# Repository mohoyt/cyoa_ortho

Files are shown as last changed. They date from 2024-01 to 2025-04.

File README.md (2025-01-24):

# CYOA (Choose Your Own Adventure) Ortho

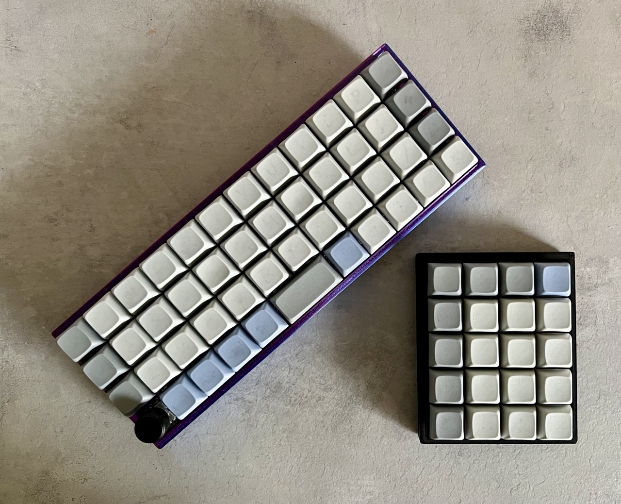
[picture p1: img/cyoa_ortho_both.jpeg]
CYOA Ortho


CYOA Ortho or Choose Your Own Adventure Ortho is a simple Pro Micro compatible ortho PCB that you can freely adjust to your preferences by snapping off rows or columns to make your perfect Ortho board. 

The board is a 5 row x 12 column board to begin with but with the perforations on the board you can make it almost any size down to 3 x 3. So you can build ortho layouts like the Preonic (5x12), Planck (4x12), Gherkin (3x10) or even a macro or num pad.

If you go with a 4 or a 5 row variant then you have the option to have 1 or 2 2u keys on the bottom row too.

A single optional rotary encoder can be added in one of 8 positions. Supports MX or choc v1 (and v2 (since CYOA v0.4)) switches. 

See the KLE layout here: [http://www.keyboard-layout-editor.com/#/gists/a172a36ed405e7bec95fd89415a75808](http://www.keyboard-layout-editor.com/#/gists/a172a36ed405e7bec95fd89415a75808)

## Where to get one

Limited PCBs are available at STHLM kb: [https://sthlmkb.com/shop/cyoa-ortho/](https://sthlmkb.com/shop/cyoa-ortho/)

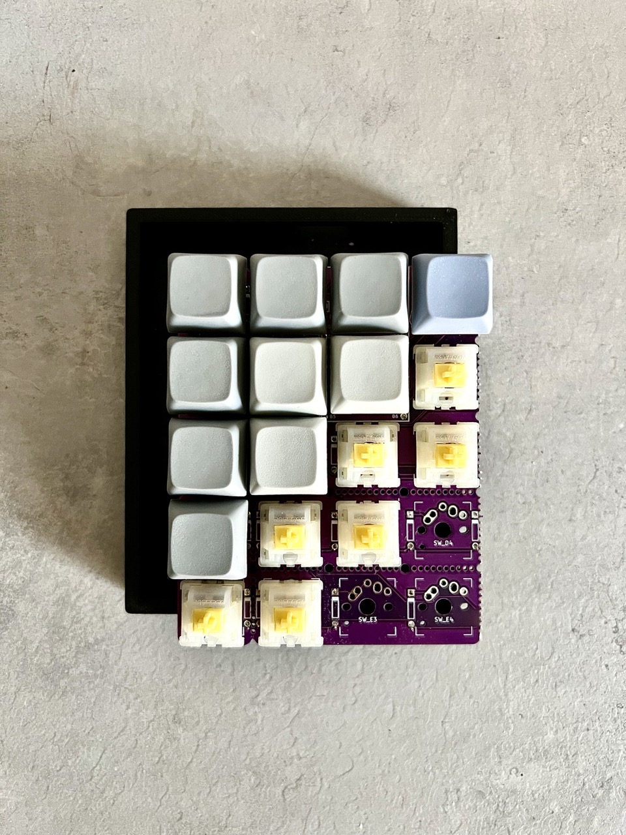
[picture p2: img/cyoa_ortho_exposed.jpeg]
CYOA Ortho


## Build instructions

These are printed on the PCB. The build is pretty simple.

1. Decide what size board you want
2. Carefully snap along perforations on PCB. It helps to use a flush cutter to help start at each end and then to use the edge of a table to assist with bending and snapping. FR4 is sharp so be careful and make sure to sand or file the edges to smoothen them
3. Solder the diodes (either side is technically fine) just make sure that you have the right orientation for them. The black stripe on the diode should line up with the white stripe on the top of the board
4. Solder the 2 switches directly above the controller. Trim the pins and isolate them with electrical tape after so that they do not short on the controller.
5. Flash and solder the controller onto the board. You want the controller to be as close as possible to the board so that it doesn't clash with any case that you're using. Make sure to plug in the board and test all the switch contacts (e.g. with tweezers) once you have done this. 
6. Install stabilisers (if you're using them), encoder (again, if you're using one) and      switches on the rest of the board.
7. Install in case. Enjoy.  

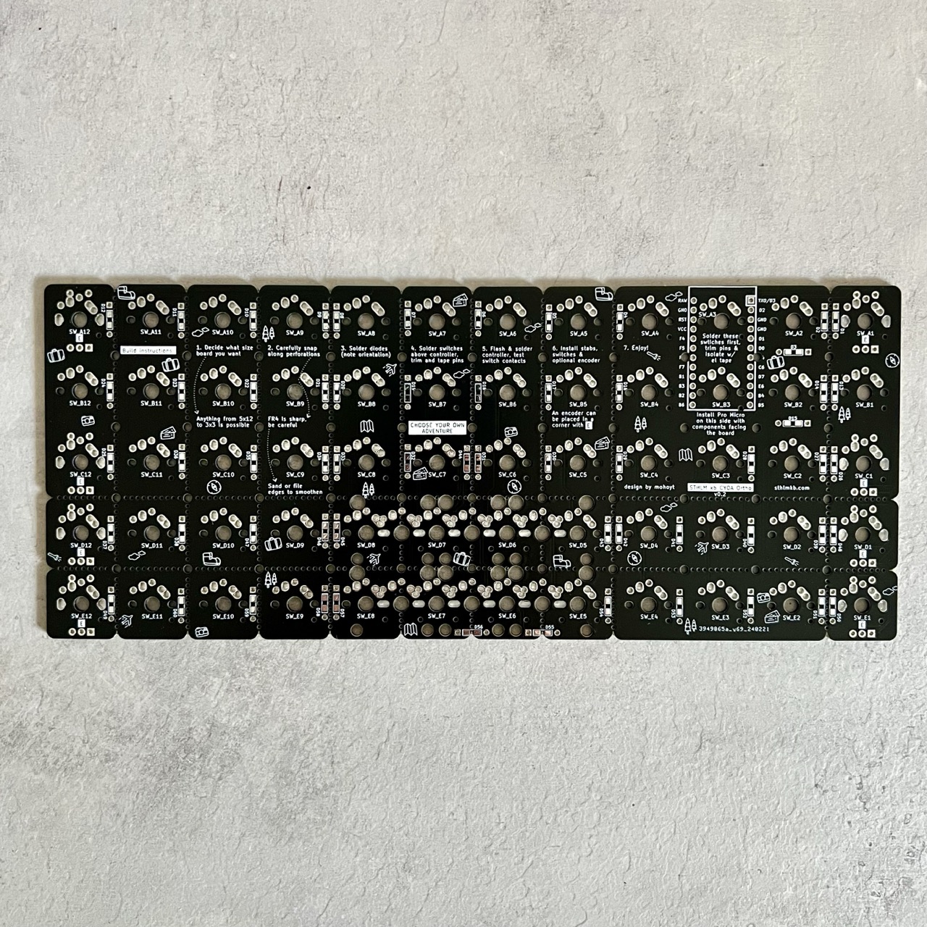
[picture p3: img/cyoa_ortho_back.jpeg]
CYOA Ortho


## Flashing instructions

See the firmware folder for more information.

There are example qmk files for 5x12 and 4x12 layouts for both QMK and Vial setups. These will need to be compiled using QMK or the Vial fork of Vial respectively. The `info.json` file contains all possible layouts so it should be possible to easily craft your layout using that as a starting point. 

## Plates

The CYOA Ortho is a bare PCB with no plate. It is theoretically possible to make a plate for it, and probably not hard either since it is a grid. A plate for a Planck or a Preonic could also be used if you have the same size.

## Cases

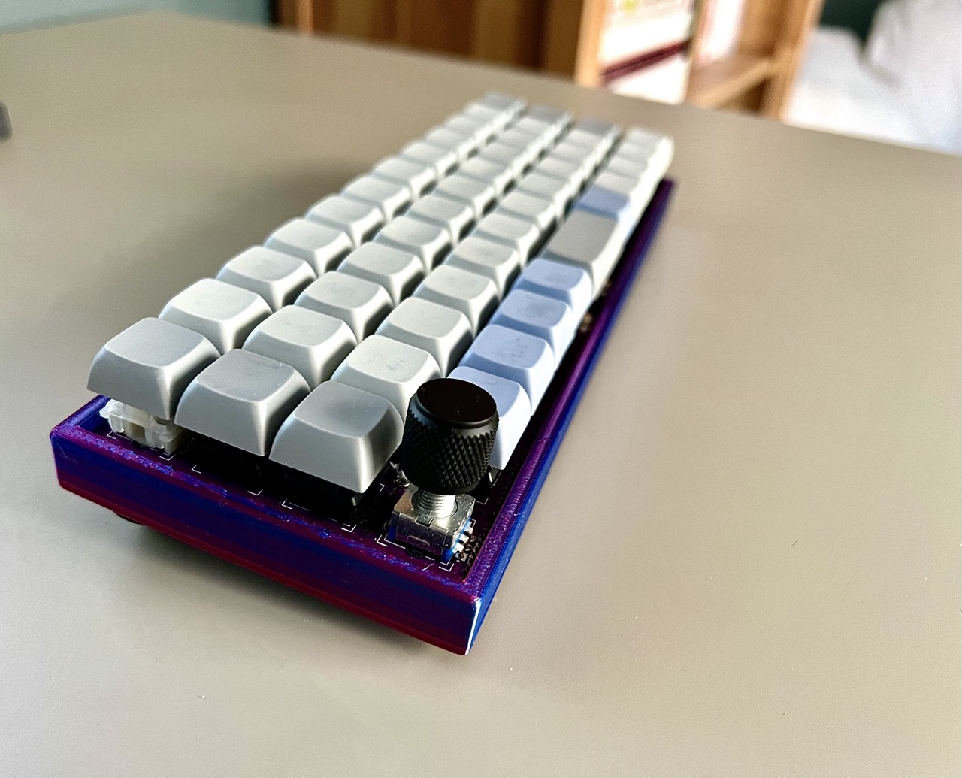
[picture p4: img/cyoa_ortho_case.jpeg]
CYOA Ortho


3d printed cases are available for CYOA Ortho. See here for more details: [https://www.printables.com/model/784492-cyoa-choose-your-own-adventure-ortho-keyboard-case](https://www.printables.com/model/784492-cyoa-choose-your-own-adventure-ortho-keyboard-case) These are tray style and attach to the M2 holes on the PCB. Cases are available for all possible size variations.

## Changelog / known issues

- Version 0.1 had the wrong size Pro Micro footprint. This is updated in v0.2
- Version 0.2 had a trace not connected fully meaning that the four leftmost keys on the 4th row would not work. This is fixed in version 0.3
- Version 0.4 now has larger centre holes for Choc v2 switches (currently untested though)

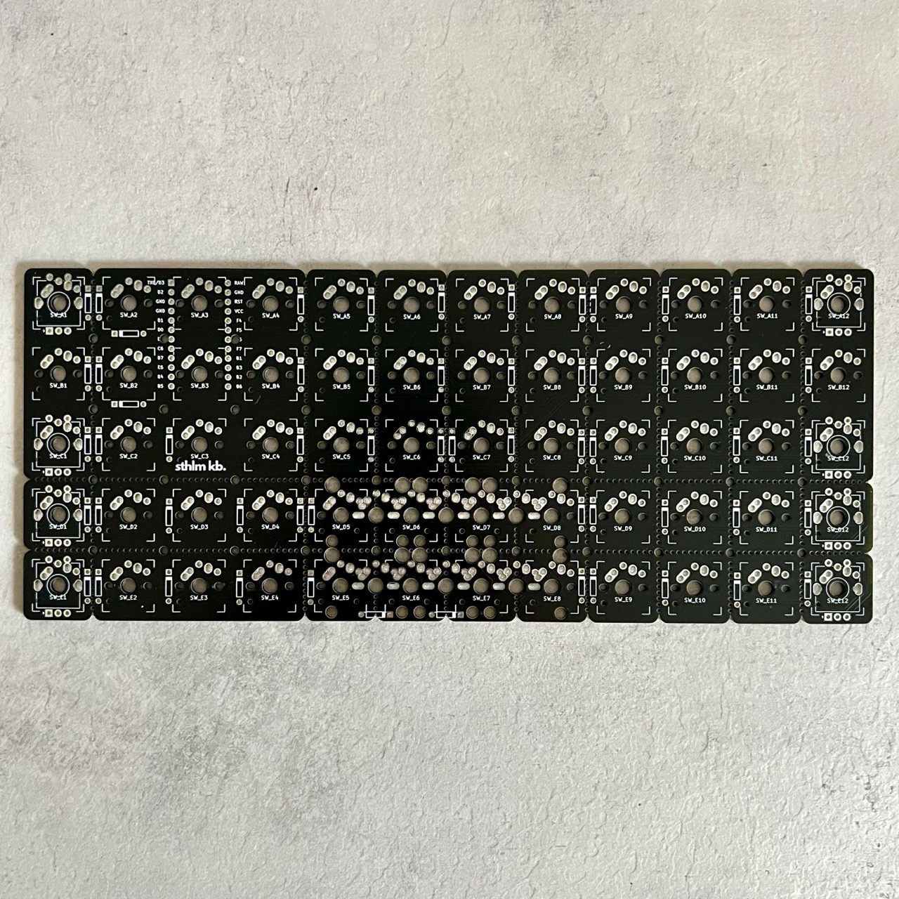
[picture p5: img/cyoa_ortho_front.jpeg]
CYOA Ortho


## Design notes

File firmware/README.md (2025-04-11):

# CYOA Ortho

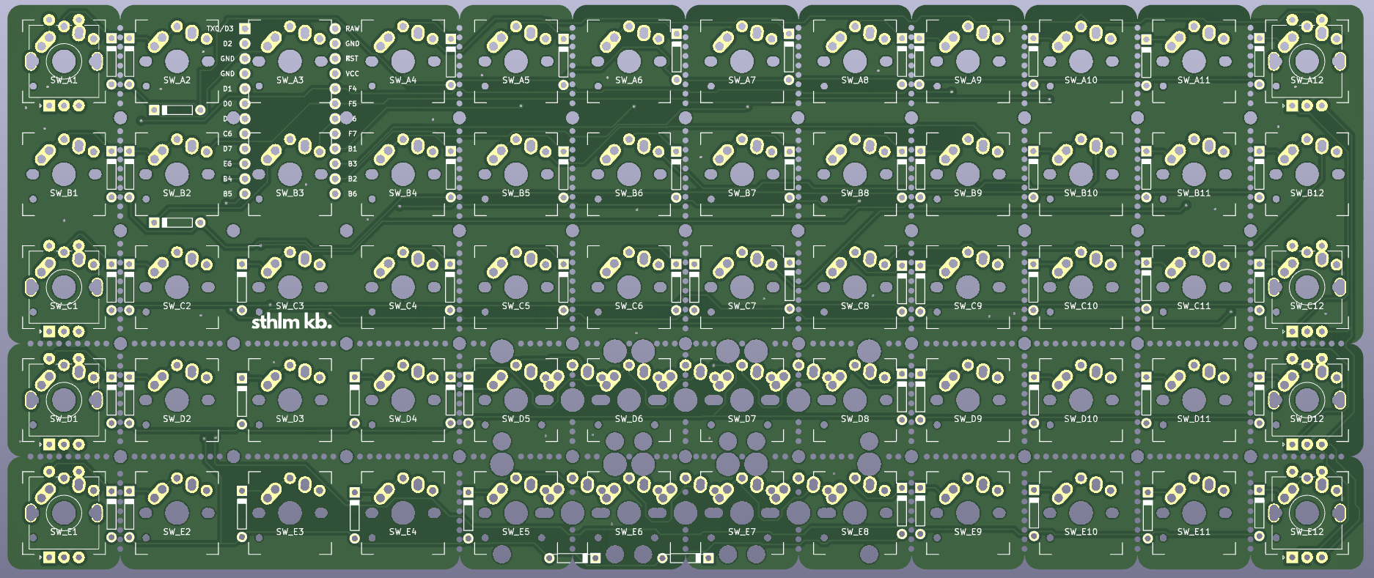
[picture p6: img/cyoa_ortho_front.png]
CYOA Ortho


## Flashing instructions

See the `cyoa_ortho` folder for the QMK source.

There are example qmk files for 5x12 and 4x12 layouts for both QMK and Vial setups. These will need to be compiled using QMK or the Vial fork of Vial respectively. The `info.json` file contains all possible layouts so it should be possible to easily craft your layout using that as a starting point. 

## Precompiled firmware

There are a couple precompiled firmware examples here that you are welcome to use: 

* QMK 5x12 layout (for Pro Micro)
* QMK 4x12 layout (for Pro Micro)
* Vial 5x12 layout (for Pro Micro)
* Vial 5x12 layout (for RP2040 Helios board)
* Vial 4x12 layout (for Pro Micro)
* Vial 4x12 layout (for RP2040 Helios board)

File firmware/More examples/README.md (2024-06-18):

# CYOA Ortho

CYOA Ortho

## More examples

This is an example of how you might repurpose the encoder pin (if you're not using encoders) to add rgb lights.

In this case I used pin D3, but you can of course change it to use the other pin D2.

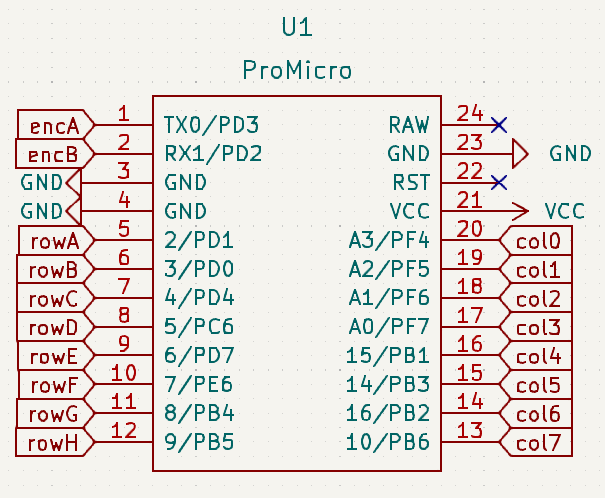
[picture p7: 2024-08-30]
img/cyoa_pinout.png

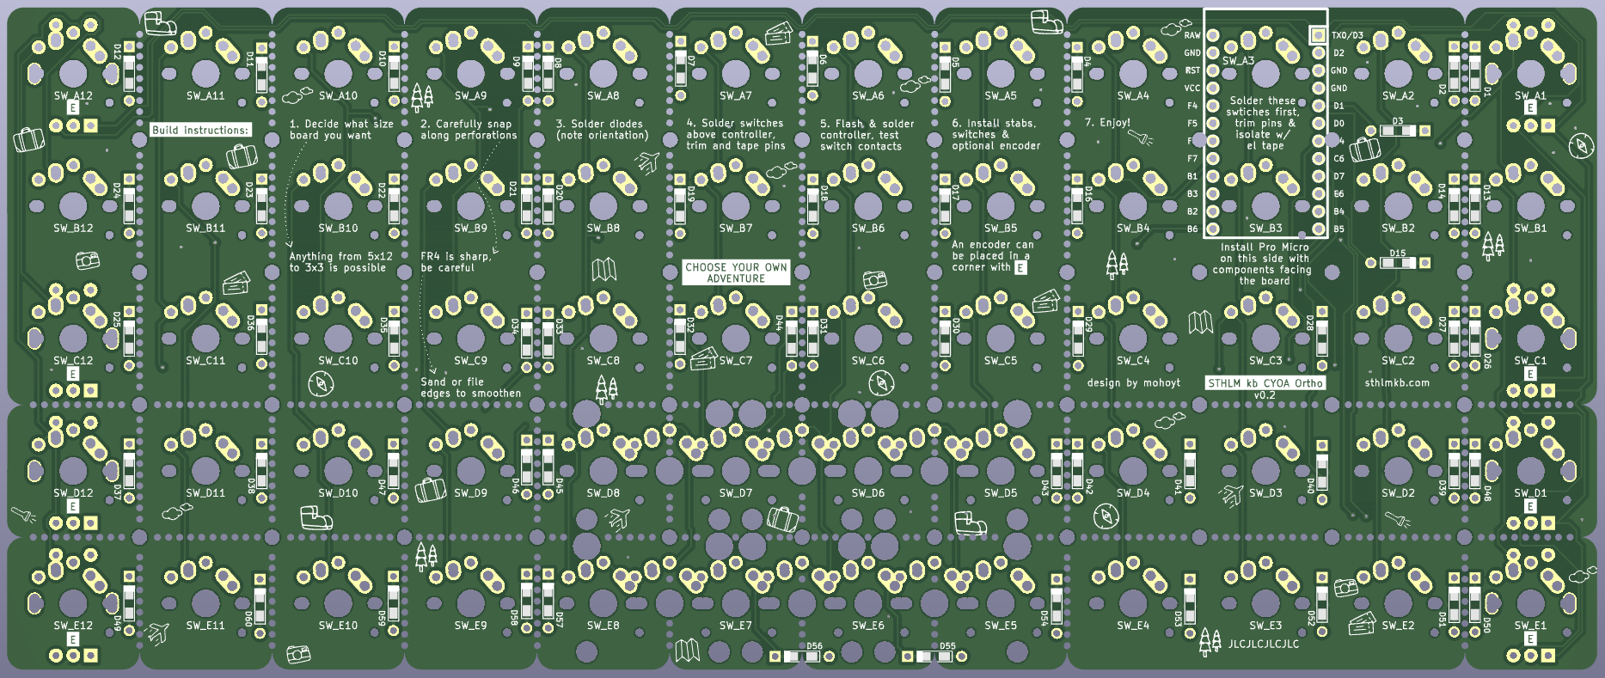
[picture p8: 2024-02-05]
img/cyoa_ortho_back.png

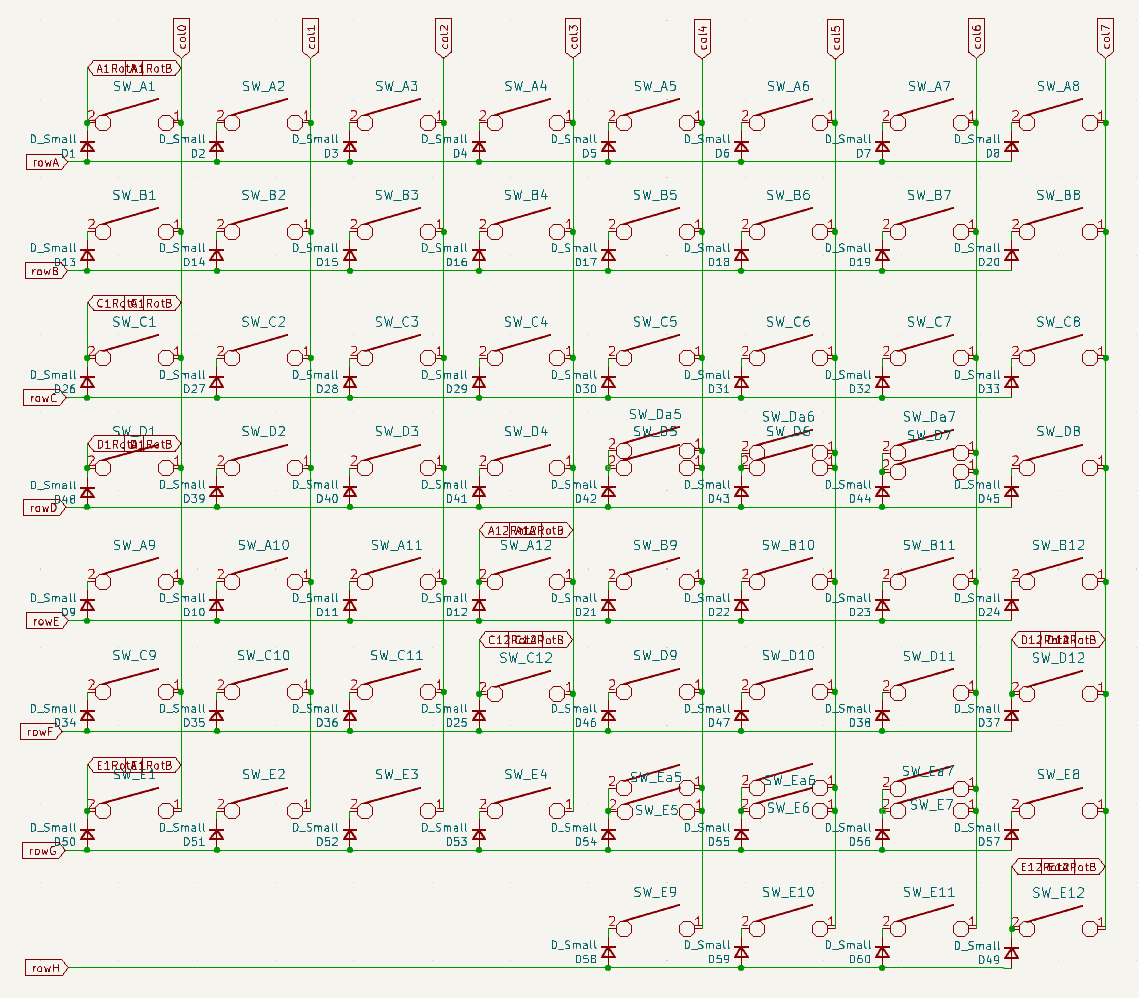
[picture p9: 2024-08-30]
img/cyoa_matrix.png

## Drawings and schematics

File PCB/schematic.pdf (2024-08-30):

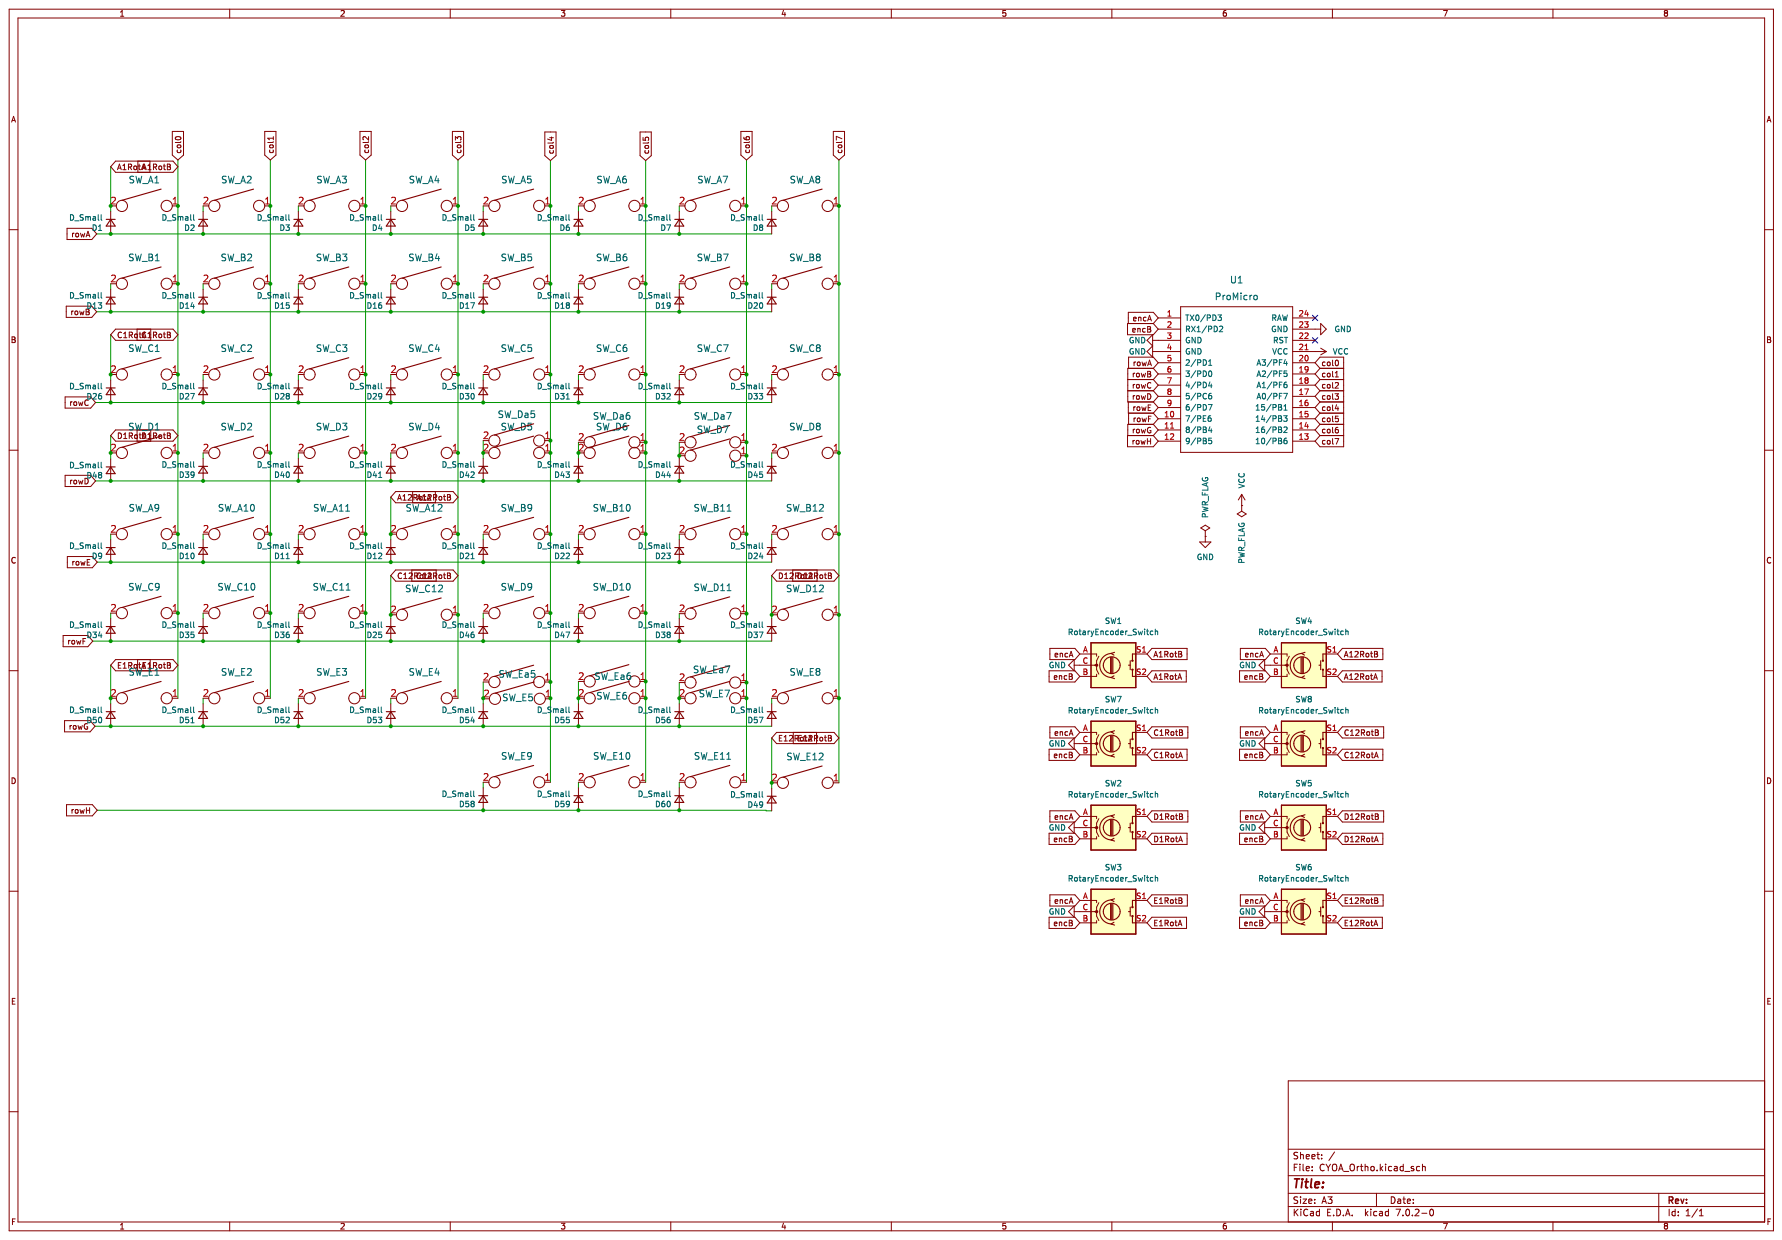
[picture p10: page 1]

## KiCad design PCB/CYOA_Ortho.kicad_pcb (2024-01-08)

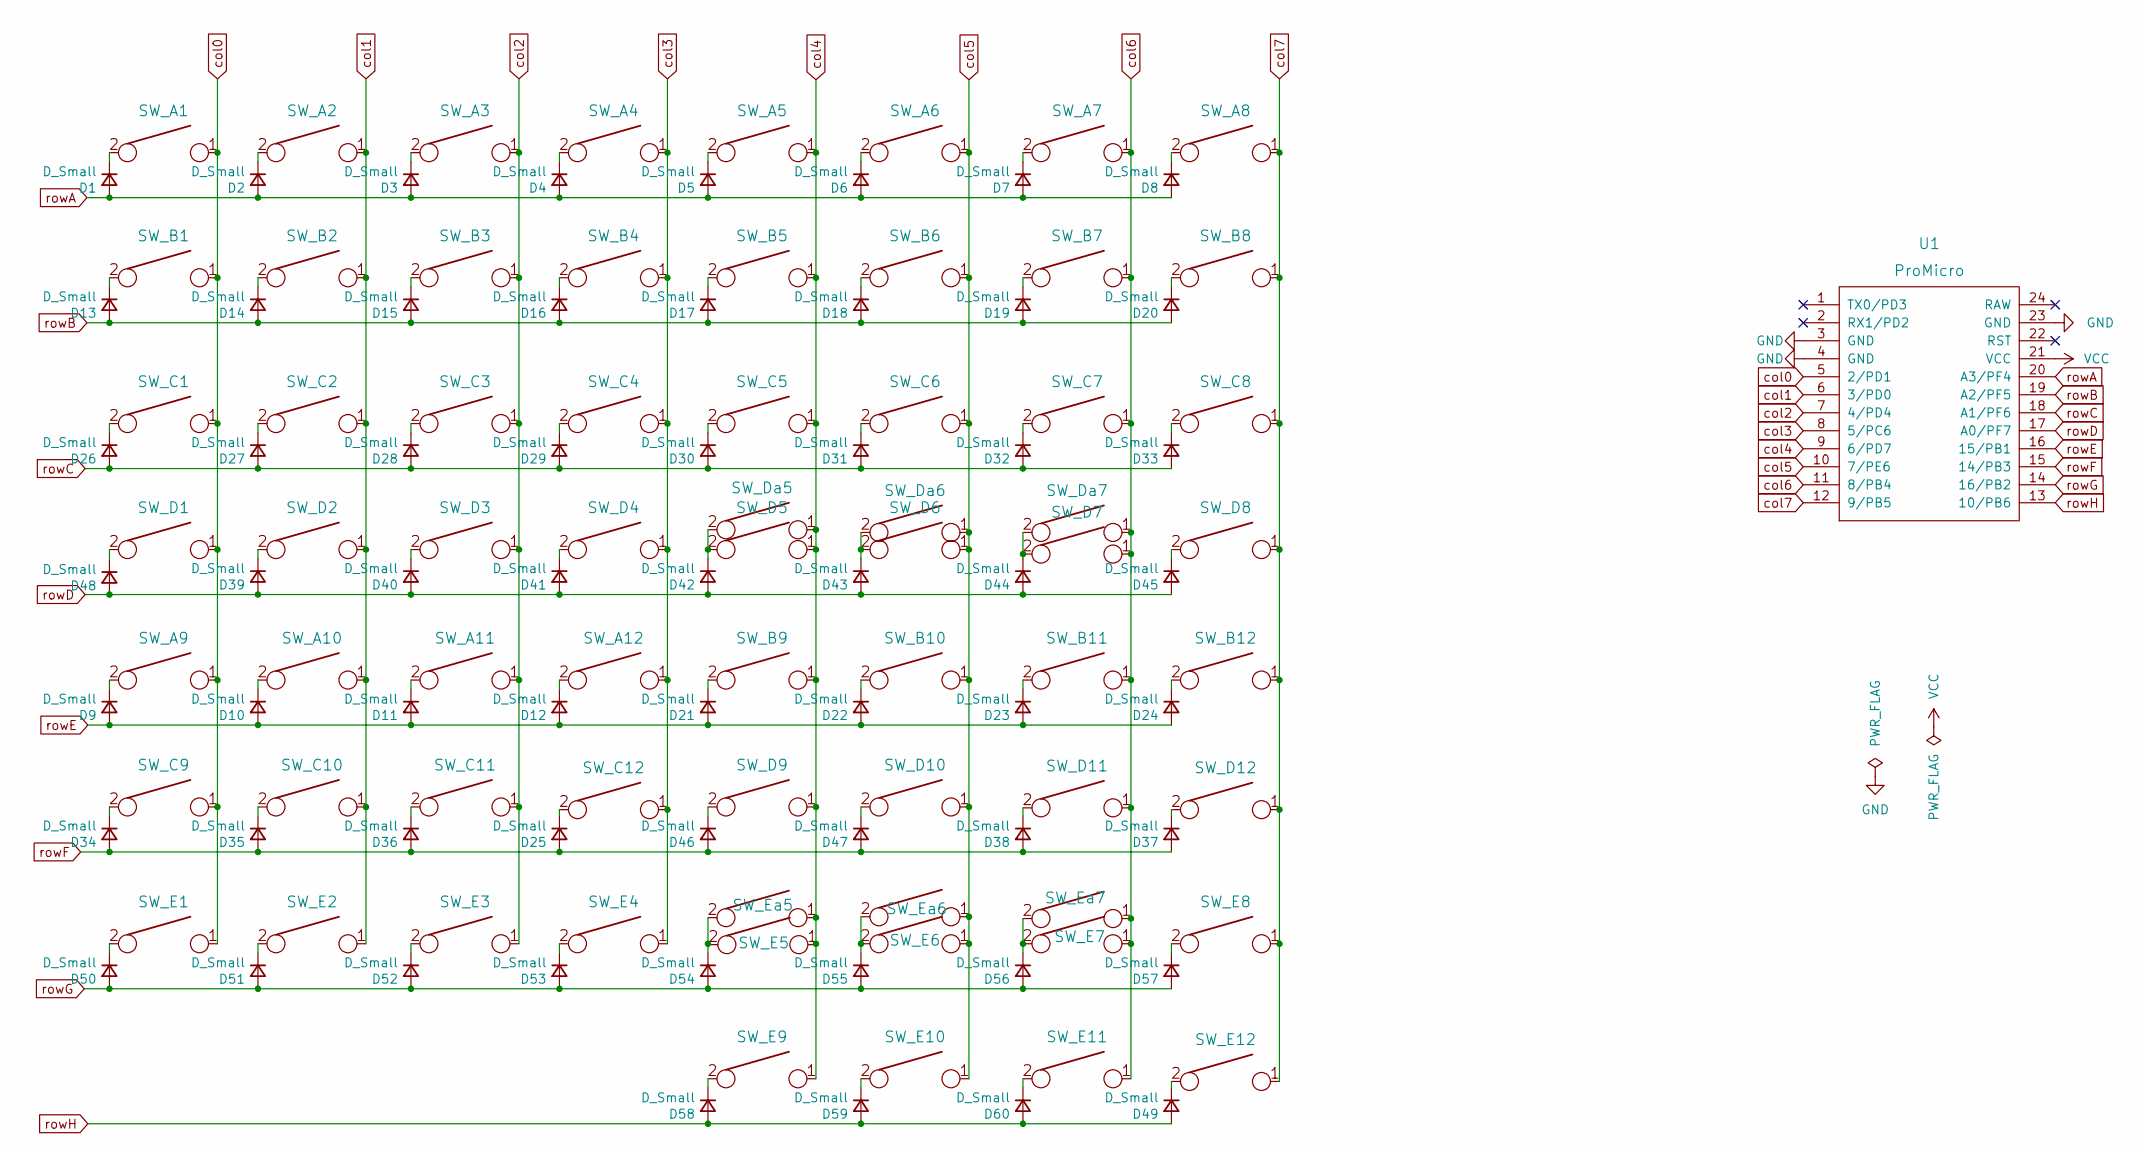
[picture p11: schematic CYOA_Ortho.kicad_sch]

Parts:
D1, D2, D3, D4, D5, D6, D7, D8, D9, D10, D11, D12, D13, D14, D15, D16, D17, D18, D19, D20, D21, D22, D23, D24, D25, D26, D27, D28, D29, D30, D31, D32, D33, D34, D35, D36, D37, D38, D39, D40, D41, D42, D43, D44, D45, D46, D47, D48, D49, D50, D51, D52, D53, D54, D55, D56, D57, D58, D59, D60: D_Small; Diode-Hybrid-Back
SW_A1, SW_A2, SW_A3, SW_A4, SW_A5, SW_A6, SW_A7, SW_A8, SW_A9, SW_A10, SW_A11, SW_A12: KEYSW; MX-Alps-Choc-1U-NoLED
SW_B1, SW_B2, SW_B3, SW_B4, SW_B5, SW_B6, SW_B7, SW_B8, SW_B9, SW_B10, SW_B11, SW_B12: KEYSW; MX-Alps-Choc-1U-NoLED
SW_C1, SW_C2, SW_C3, SW_C4, SW_C5, SW_C6, SW_C7, SW_C8, SW_C9, SW_C10, SW_C11, SW_C12: KEYSW; MX-Alps-Choc-1U-NoLED
SW_D1, SW_D2, SW_D3, SW_D4, SW_D5, SW_D6, SW_D7, SW_D8, SW_D9, SW_D10, SW_D11, SW_D12: KEYSW; MX-Alps-Choc-1U-NoLED
SW_Da5, SW_Da6, SW_Da7: KEYSW; MX-Alps-Choc-2U-StabFlip-NoLED
SW_E1, SW_E2, SW_E3, SW_E4, SW_E5, SW_E6, SW_E7, SW_E8, SW_E9, SW_E10, SW_E11, SW_E12: KEYSW; MX-Alps-Choc-1U-NoLED
SW_Ea5, SW_Ea6, SW_Ea7: KEYSW; MX-Alps-Choc-2U-StabFlip-NoLED
U1: ProMicro; ArduinoProMicro-Mini-USB

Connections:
GND: U1.3 (GND), U1.4 (GND), U1.23 (GND)
unnamed: D1.1 (K), SW_A1.2
unnamed: D2.1 (K), SW_A2.2
unnamed: D3.1 (K), SW_A3.2
unnamed: D4.1 (K), SW_A4.2
unnamed: D5.1 (K), SW_A5.2
unnamed: D6.1 (K), SW_A6.2
unnamed: D7.1 (K), SW_A7.2
unnamed: D8.1 (K), SW_A8.2
unnamed: D9.1 (K), SW_A9.2
unnamed: D10.1 (K), SW_A10.2
unnamed: D11.1 (K), SW_A11.2
unnamed: D12.1 (K), SW_A12.2
unnamed: D13.1 (K), SW_B1.2
unnamed: D14.1 (K), SW_B2.2
unnamed: D15.1 (K), SW_B3.2
unnamed: D16.1 (K), SW_B4.2
unnamed: D17.1 (K), SW_B5.2
unnamed: D18.1 (K), SW_B6.2
unnamed: D19.1 (K), SW_B7.2
unnamed: D20.1 (K), SW_B8.2
unnamed: D21.1 (K), SW_B9.2
unnamed: D22.1 (K), SW_B10.2
unnamed: D23.1 (K), SW_B11.2
unnamed: D24.1 (K), SW_B12.2
unnamed: D25.1 (K), SW_C12.2
unnamed: D26.1 (K), SW_C1.2
unnamed: D27.1 (K), SW_C2.2
unnamed: D28.1 (K), SW_C3.2
unnamed: D29.1 (K), SW_C4.2
unnamed: D30.1 (K), SW_C5.2
unnamed: D31.1 (K), SW_C6.2
unnamed: D32.1 (K), SW_C7.2
unnamed: D33.1 (K), SW_C8.2
unnamed: D34.1 (K), SW_C9.2
unnamed: D35.1 (K), SW_C10.2
unnamed: D36.1 (K), SW_C11.2
unnamed: D37.1 (K), SW_D12.2
unnamed: D38.1 (K), SW_D11.2
unnamed: D39.1 (K), SW_D2.2
unnamed: D40.1 (K), SW_D3.2
unnamed: D41.1 (K), SW_D4.2
unnamed: D42.1 (K), SW_D5.2, SW_Da5.2
unnamed: D43.1 (K), SW_D6.2, SW_Da6.2
unnamed: D44.1 (K), SW_D7.2, SW_Da7.2
unnamed: D45.1 (K), SW_D8.2
unnamed: D46.1 (K), SW_D9.2
unnamed: D47.1 (K), SW_D10.2
unnamed: D48.1 (K), SW_D1.2
unnamed: D49.1 (K), SW_E12.2
unnamed: D50.1 (K), SW_E1.2
unnamed: D51.1 (K), SW_E2.2
unnamed: D52.1 (K), SW_E3.2
unnamed: D53.1 (K), SW_E4.2
unnamed: D54.1 (K), SW_E5.2, SW_Ea5.2
unnamed: D55.1 (K), SW_E6.2, SW_Ea6.2
unnamed: D56.1 (K), SW_E7.2, SW_Ea7.2
unnamed: D57.1 (K), SW_E8.2
unnamed: D58.1 (K), SW_E9.2
unnamed: D59.1 (K), SW_E10.2
unnamed: D60.1 (K), SW_E11.2
VCC: U1.21 (VCC)
col0: SW_A1.1, SW_A9.1, SW_B1.1, SW_C1.1, SW_C9.1, SW_D1.1, SW_E1.1, U1.5 (2/PD1)
col1: SW_A2.1, SW_A10.1, SW_B2.1, SW_C2.1, SW_C10.1, SW_D2.1, SW_E2.1, U1.6 (3/PD0)
col2: SW_A3.1, SW_A11.1, SW_B3.1, SW_C3.1, SW_C11.1, SW_D3.1, SW_E3.1, U1.7 (4/PD4)
col3: SW_A4.1, SW_A12.1, SW_B4.1, SW_C4.1, SW_C12.1, SW_D4.1, SW_E4.1, U1.8 (5/PC6)
col4: SW_A5.1, SW_B5.1, SW_B9.1, SW_C5.1, SW_D5.1, SW_D9.1, SW_Da5.1, SW_E5.1, SW_E9.1, SW_Ea5.1, U1.9 (6/PD7)
col5: SW_A6.1, SW_B6.1, SW_B10.1, SW_C6.1, SW_D6.1, SW_D10.1, SW_Da6.1, SW_E6.1, SW_E10.1, SW_Ea6.1, U1.10 (7/PE6)
col6: SW_A7.1, SW_B7.1, SW_B11.1, SW_C7.1, SW_D7.1, SW_D11.1, SW_Da7.1, SW_E7.1, SW_E11.1, SW_Ea7.1, U1.11 (8/PB4)
col7: SW_A8.1, SW_B8.1, SW_B12.1, SW_C8.1, SW_D8.1, SW_D12.1, SW_E8.1, SW_E12.1, U1.12 (9/PB5)
rowA: D1.2 (A), D2.2 (A), D3.2 (A), D4.2 (A), D5.2 (A), D6.2 (A), D7.2 (A), D8.2 (A), U1.20 (A3/PF4)
rowB: D13.2 (A), D14.2 (A), D15.2 (A), D16.2 (A), D17.2 (A), D18.2 (A), D19.2 (A), D20.2 (A), U1.19 (A2/PF5)
rowC: D26.2 (A), D27.2 (A), D28.2 (A), D29.2 (A), D30.2 (A), D31.2 (A), D32.2 (A), D33.2 (A), U1.18 (A1/PF6)
rowD: D39.2 (A), D40.2 (A), D41.2 (A), D42.2 (A), D43.2 (A), D44.2 (A), D45.2 (A), D48.2 (A), U1.17 (A0/PF7)
rowE: D9.2 (A), D10.2 (A), D11.2 (A), D12.2 (A), D21.2 (A), D22.2 (A), D23.2 (A), D24.2 (A), U1.16 (15/PB1)
rowF: D25.2 (A), D34.2 (A), D35.2 (A), D36.2 (A), D37.2 (A), D38.2 (A), D46.2 (A), D47.2 (A), U1.15 (14/PB3)
rowG: D50.2 (A), D51.2 (A), D52.2 (A), D53.2 (A), D54.2 (A), D55.2 (A), D56.2 (A), D57.2 (A), U1.14 (16/PB2)
rowH: D49.2 (A), D58.2 (A), D59.2 (A), D60.2 (A), U1.13 (10/PB6)

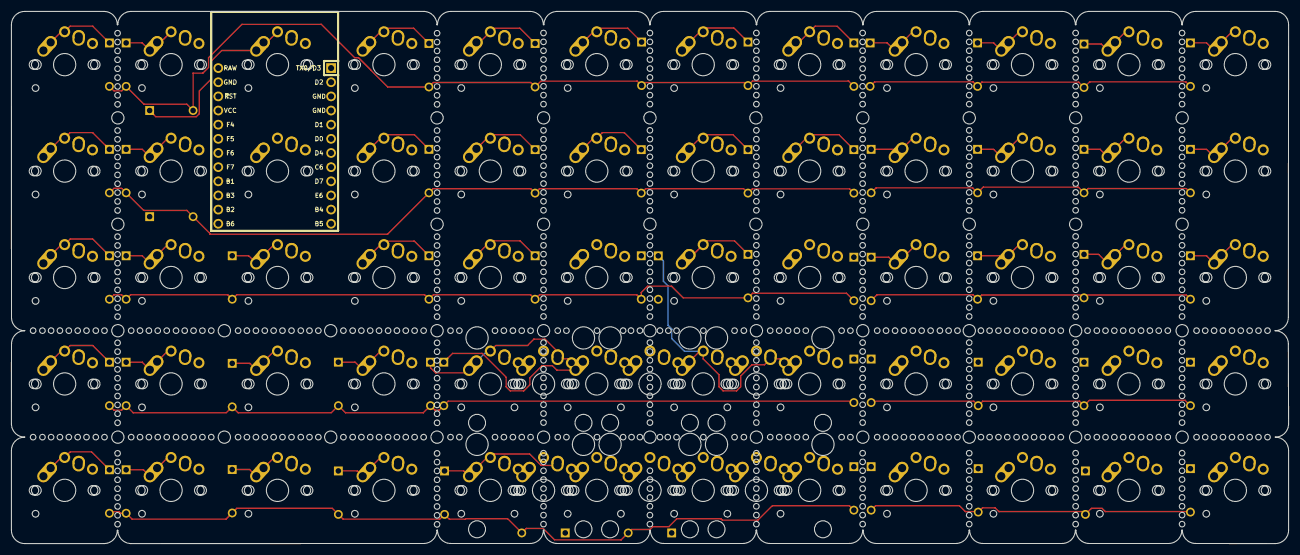
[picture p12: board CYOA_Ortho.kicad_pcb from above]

Board: 2 copper layers, 229.2 x 95.5 mm, 127 parts (1 on the bottom side), 77 nets.

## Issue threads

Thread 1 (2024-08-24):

Trouble flashing the firmware

rodgzilla, 2024-08-24:
Hi!

I am having troubles flashing the firmware onto the controller. I am quite new to QMK so there are probably things that I don't understand.

I've run the following command and this is the result I am getting.

```
 make sthlmkb/cyoa_ortho:default
```

```
QMK Firmware 0.25.22
make: *** No rule to make target 'sthlmkb/cyoa_ortho:default'. Stop.
|
| QMK's make format is:
|     make keyboard_folder:keymap_folder[:target]
|
| Where `keyboard_folder` is the path to the keyboard relative to
| `qmk_firmware/keyboards/`, and `keymap_folder` is the name of the
| keymap folder under that board's `keymaps/` directory.
|
| Examples:
|     keyboards/dz60, keyboards/dz60/keymaps/default
|       -> make dz60:default
|       -> qmk compile -kb dz60 -km default
|     keyboards/planck/rev6, keyboards/planck/keymaps/default
|       -> make planck/rev6:default:flash
|       -> qmk flash -kb planck/rev6 -km default
|
```

I think that my QMK environment is setup properly because I have managed to flash other keyboards in the past.

I have also tried copying the content of folder `cyoa_ortho/firmware/cyoa_ortho` to the `keyboards/sthlmkb` in my QMK folder but I keep getting the same message.

Could you please give me some pointers?

mohoyt, 2024-08-25:
Hey!

A couple things to try:
* Are you sure that you're in the `qmk_firmware` directory when you run the command?
* Have you copied over the `default` keymap too? I assume that you copied that over automatically when you got the whole folder, but just want to check!
* Is your QMK installed correctly? You can run `qmk doctor` to check this
* Have you tried running `qmk compile -kb sthlmkb/cyoa_ortho -km default` instead? That also worked for me

Maybe as another option is updating QMK so that you have the latest version (though it looks like you do from above) or reinstalling it if that doesn't work.

Let me know how you get on and hopefully we can figure this out!

mohoyt, 2025-01-24:
Closed due to inactivity.

Closed 2025-01-24.

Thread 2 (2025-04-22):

Question: stabilizers

timvyy, 2025-04-22:
Hey,

do I need screw in or snap in stabilizers for the CYOA keyboard PCB?

Thanks

mohoyt, 2025-04-23:
Hey! For the 2u keys you can use either, they just need to be PCB mount ones and not plate mount.

timvyy, 2025-04-23:
Thanks!

Closed 2025-04-23.

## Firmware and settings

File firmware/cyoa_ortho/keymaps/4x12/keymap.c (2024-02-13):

/* Copyright 2024 mohoyt
 *
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
 * You should have received a copy of the GNU General Public License
 * along with this program.  If not, see <http://www.gnu.org/licenses/>.
 */
#include QMK_KEYBOARD_H

enum layers {
  _QWERTY,
  _LOWER,
  _RAISE
};

const uint16_t PROGMEM keymaps[][MATRIX_ROWS][MATRIX_COLS] = {

/* Qwerty
 * ,-----------------------------------------------------------------------------------.
 * | Esc  |   Q  |   W  |   E  |   R  |   T  |   Y  |   U  |   I  |   O  |   P  | Bcsp |
 * |------+------+------+------+------+-------------+------+------+------+------+------|
 * | Tab  |   A  |   S  |   D  |   F  |   G  |   H  |   J  |   K  |   L  |   ;  |  "   |
 * |------+------+------+------+------+------|------+------+------+------+------+------|
 * | Shift|   Z  |   X  |   C  |   V  |   B  |   N  |   M  |   ,  |   .  |   /  |Enter |
 * |------+------+------+------+------+------+------+------+------+------+------+------|
 * | Mute | Ctrl | Alt  | GUI  |Lower |    Space    |Raise | Left | Down |  Up  |Right |
 * `-----------------------------------------------------------------------------------'
 */
[_QWERTY] = LAYOUT_4x12(
  KC_ESC,  KC_Q,    KC_W,    KC_E,    KC_R,    KC_T,    KC_Y,    KC_U,    KC_I,    KC_O,    KC_P,    KC_BSPC,
  KC_TAB,  KC_A,    KC_S,    KC_D,    KC_F,    KC_G,    KC_H,    KC_J,    KC_K,    KC_L,    KC_SCLN, KC_QUOT,
  KC_LSFT, KC_Z,    KC_X,    KC_C,    KC_V,    KC_B,    KC_N,    KC_M,    KC_COMM, KC_DOT,  KC_SLSH, KC_ENT,
  KC_MUTE, KC_LCTL, KC_LALT, KC_LGUI, MO(1),   KC_SPC,  KC_SPC,  MO(2),   KC_LEFT, KC_DOWN, KC_UP,   KC_RGHT
),

/* Lower
 * ,-----------------------------------------------------------------------------------.
 * |   ~  |   !  |   @  |   #  |   $  |   %  |   ^  |   &  |   *  |   (  |   )  | Del  |
 * |------+------+------+------+------+-------------+------+------+------+------+------|
 * | Del  |  F1  |  F2  |  F3  |  F4  |  F5  |  F6  |   _  |   +  |   {  |   }  |  |   |
 * |------+------+------+------+------+------|------+------+------+------+------+------|
 * |      |  F7  |  F8  |  F9  |  F10 |  F11 |  F12 |ISO ~ |ISO | | Home | End  |      |
 * |------+------+------+------+------+------+------+------+------+------+------+------|
 * |      |      |      |      |      |             |      | Next | Vol- | Vol+ | Play |
 * `-----------------------------------------------------------------------------------'
 */
[_LOWER] = LAYOUT_4x12(
  KC_TILD, KC_EXLM, KC_AT,   KC_HASH, KC_DLR,  KC_PERC, KC_CIRC, KC_AMPR, KC_ASTR, KC_LPRN, KC_RPRN, KC_DEL,
  KC_DEL,  KC_F1,   KC_F2,   KC_F3,   KC_F4,   KC_F5,   KC_F6,   KC_UNDS, KC_PLUS, KC_LCBR, KC_RCBR, KC_PIPE,
  _______, KC_F7,   KC_F8,   KC_F9,   KC_F10,  KC_F11,  KC_F12,S(KC_NUHS),S(KC_NUBS),KC_HOME, KC_END, _______,
  _______, _______, _______, _______, _______, _______, _______, _______, KC_MNXT, KC_VOLD, KC_VOLU, KC_MPLY
),

/* Raise
 * ,-----------------------------------------------------------------------------------.
 * |   `  |   1  |   2  |   3  |   4  |   5  |   6  |   7  |   8  |   9  |   0  | Del  |
 * |------+------+------+------+------+-------------+------+------+------+------+------|
 * | Del  |  F1  |  F2  |  F3  |  F4  |  F5  |  F6  |   -  |   =  |   [  |   ]  |  \   |
 * |------+------+------+------+------+------|------+------+------+------+------+------|
 * |      |  F7  |  F8  |  F9  |  F10 |  F11 |  F12 |ISO # |ISO / | Pg Up| Pg Dn|      |
 * |------+------+------+------+------+------+------+------+------+------+------+------|
 * |      |      |      |      |      |             |      | Next | Vol- | Vol+ | Play |
 * `-----------------------------------------------------------------------------------'
 */
[_RAISE] = LAYOUT_4x12(
  KC_GRV,  KC_1,    KC_2,    KC_3,    KC_4,    KC_5,    KC_6,    KC_7,    KC_8,    KC_9,    KC_0,    KC_DEL,
  KC_DEL,  KC_F1,   KC_F2,   KC_F3,   KC_F4,   KC_F5,   KC_F6,   KC_MINS, KC_EQL,  KC_LBRC, KC_RBRC, KC_BSLS,
  _______, KC_F7,   KC_F8,   KC_F9,   KC_F10,  KC_F11,  KC_F12,  KC_NUHS, KC_NUBS, KC_PGUP, KC_PGDN, _______,
  _______, _______, _______, _______, _______, _______, _______, _______, KC_MNXT, KC_VOLD, KC_VOLU, KC_MPLY
)

};

#if defined(ENCODER_MAP_ENABLE)
const uint16_t PROGMEM encoder_map[][NUM_ENCODERS][2] = {
    [0] =   { ENCODER_CCW_CW(KC_VOLD, KC_VOLU)  },
    [1] =   { ENCODER_CCW_CW(KC_MPRV, KC_MNXT)  },
    [2] =   { ENCODER_CCW_CW(KC_MPRV, KC_MNXT)  }
    //                  Encoder 1
};
#endif

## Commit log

2023-02-02 kicad project started
    [Planckonic.kicad_pcb, Planckonic.kicad_sch]
2023-02-02 schematic mostly done
    [Planckonic.kicad_sch]
2023-02-05 schematic improvements
    [Planckonic.kicad_sch]
2023-02-05 schematic done, layout started
    [Planckonic.kicad_pcb, Planckonic.kicad_sch]
2023-10-09 Slight cleanup
    [CYOA_Ortho.kicad_pcb, CYOA_Ortho.kicad_sch, Planckonic.kicad_pcb]
2024-01-08 Layout done, routing started
    [CYOA_Ortho.kicad_pcb]
2024-01-09 routing pretty much done
    [CYOA_Ortho.kicad_sch]
2024-01-09 Silkscreen mostly done
    [CYOA_Ortho.kicad_sch]
2024-01-11 Version 0.1 done and sent to fabrication
    [CYOA_Ortho-B_Cu.gbl, CYOA_Ortho-B_Mask.gbs, CYOA_Ortho-B_Paste.gbp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]
2024-01-31 Pro micro footprint fixed v0.2 done
    [CYOA_Ortho-B_Cu.gbl, CYOA_Ortho-B_Mask.gbs, CYOA_Ortho-B_Paste.gbp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]
2024-01-31 Pro micro footprint tweaked slightly to clean up front silkscreen
    [CYOA_Ortho-B_Cu.gbl, CYOA_Ortho-B_Mask.gbs, CYOA_Ortho-B_Paste.gbp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]
2024-01-31 v0.2 gerbers updated
2024-02-03 Readme and ground plane updated
    [CYOA_Ortho-B_Cu.gbl, CYOA_Ortho-B_Mask.gbs, CYOA_Ortho-B_Paste.gbp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]
2024-02-05 Added some missing M2 mounting holes near the controller and updated v0.2
    [CYOA_Ortho-B_Cu.gbl, CYOA_Ortho-B_Mask.gbs, CYOA_Ortho-B_Paste.gbp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]
2024-03-28 Version 0.3 with fixed trace issue
    [CYOA_Ortho-B_Cu.gbl, CYOA_Ortho-B_Mask.gbs, CYOA_Ortho-B_Paste.gbp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]
2024-06-18 Examples with RGB lights in place of the encoder added to firmware
2024-08-30 Schematic pdf and images added
2024-12-02 Updated readme to highlight lack of support for choc v2 switches
2025-01-24 Update to Kicad v8 and enlarged centre hole of switch to support Choc v2 switches too (this is in v0.4)
    [CYOA_Ortho-B_Cu.gbl, CYOA_Ortho-B_Mask.gbs, CYOA_Ortho-B_Paste.gbp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]
2025-04-13 New no encoder 5x12 firmware files added
2025-07-27 New precompiled firmware for 4x12 no encoder git pudh

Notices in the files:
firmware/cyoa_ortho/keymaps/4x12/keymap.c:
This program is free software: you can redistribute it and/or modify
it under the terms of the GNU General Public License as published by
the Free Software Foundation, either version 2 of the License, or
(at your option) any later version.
